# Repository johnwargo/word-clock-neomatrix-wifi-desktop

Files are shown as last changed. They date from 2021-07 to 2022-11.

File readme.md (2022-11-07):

# Word Clock NeoMatrix Wi-Fi Desktop

This repository contains a forked version of the [WORD CLOCK - NeoMatrix 8x8 Desktop Edition](https://github.com/andydoro/WordClock-NeoMatrix8x8) project by [Andy Doro](https://andydoro.com/) & [Dano Wall](https://github.com/danowall).  

I forked the project because my personal implementation of the clock got way behind time-wise, so I decided to rebuild the code for a Wi-Fi enabled device (Adafruit Feather) so it can periodically update the real-time clock (RTC) using an [Internet Time Server](https://tf.nist.gov/tf-cgi/servers.cgi) and [Network Time Protocol](https://en.wikipedia.org/wiki/Network_Time_Protocol) (NTP). 

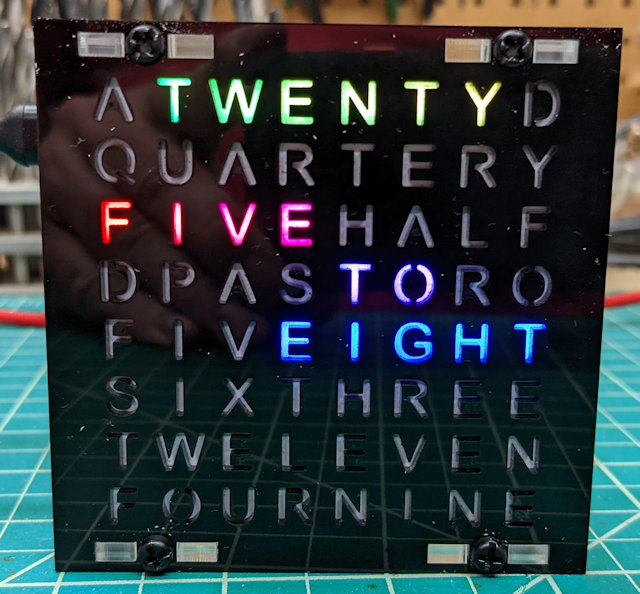
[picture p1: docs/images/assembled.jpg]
Finished Project


Here's some details for the original project:

## Original Project

* [Andy Doro Word Clock Desktop](https://andydoro.com/wordclockdesktop/)
* [Adafruit Learn Guide](https://learn.adafruit.com/neomatrix-8x8-word-clock/)
* [GitHub Repository](https://github.com/andydoro/WordClock-NeoMatrix8x8)

### Clock Grid Pattern

``` text
A T W E N T Y D
Q U A R T E R Y
F I V E H A L F
D P A S T O R O
F I V E I G H T
S I X T H R E E
T W E L E V E N
F O U R N I N E
```

Acknowledgements:

  - Thanks [Dano](https://github.com/danowall) for faceplate / 3D models & project inspiration! 

## Hardware Components

This updated version of the project uses the following hardware components:

* [Adafruit HUZZAH32 – ESP32 Feather Board](https://learn.adafruit.com/adafruit-huzzah32-esp32-feather). Make sure you order the device with 'Loose headers', you'll need those headers for the DS3231 Precision RTC FeatherWing.
* [DS3231 Precision RTC FeatherWing - RTC Add-on For Feather Boards](https://www.adafruit.com/product/3028).
* [CR1220 12mm Diameter - 3V Lithium Coin Cell Battery](https://www.adafruit.com/product/380).
* [NeoPixel NeoMatrix 8x8](https://www.adafruit.com/products/1487).
* (Optional) [Short Feather Male Headers - 12-pin and 16-pin Male Header Set](https://www.adafruit.com/product/3002); these should already come with the Feather Huzzah32.
* [Header Kit for Feather - 12-pin and 16-pin Female Header Set](https://www.adafruit.com/product/2886).
* LASER cut faceplate & enclosure (I'm using all capital letters for LASER because it is, after all, an acronym).
* Enclosure Assembly Parts:
  * 10 @ M3x12mm machine screws (bolts); enclosure assembly.
  * 4 @ M3x8mm machine screws (bolts); mounting the LED Matrix to the enclosure.
  * 14 @ M3 nuts; enclosure assembly.
  * 4 @ M2.5x12mm machine screws (bolts); mounting the Feather device to the enclosure.
  * 4 @ M2.5 nuts; mounting the Feather device to the enclosure.

## Instructions

To keep this readme as simple as possible, I moved the assembly and software configuration instructions into separate files:

1. [Electronics Assembly](docs/electronics-assembly.md)
2. [Electronics Testing](docs/electronics-testing.md)
3. [Enclosure Assembly](docs/enclosure-assembly.md)
4. [Software Configuration](docs/software.md)

## Project Updates

I've tried to maintain as much of the original code as possible; so far, I made the following changes:

* Move the sketch's configuration settings to an external file I could exclude from the repo. By doing this, and by including a separate file users must rename before compiling the project, users can refresh their local code base from the public repository without wiping out their configuration settings. 
* Removed the `DateTime theTime` global variable and declared it locally and passed it around as needed (global variables are bad).
* Added more comments explaining the code in more detail (for users who want to better understand what's happening within the sketch).
* Renamed the project files using dashes instead of camelCase; this names them consistently and, when you're working on systems where file name case matters, you won't have to deal with anything in upper case.
* Added an test sketch to quickly validate the electronics assembly before configuring and deploying the main clock sketch.
* Updated the enclosure files to accommodate the Adafruit Feather board and added the files to a separate folder in the repo
* Added LASER cutter files for a 12-inch clock face for a wall mounted unit.

For this version of the project, I selected the [Feather Huzzah 32](https://www.adafruit.com/product/3405); I became a big fan of the board's ESP32 chipset last year, so I knew the selected board had enough horsepower and memory for anything I needed.  For the Real-time Clock (RTC) board, I selected the [DS3231 Precision RTC FeatherWing - RTC Add-on For Feather Boards](https://www.adafruit.com/product/3028); its a high precision board that maintains time accuracy in different temperature conditions. 

Another reason I like this board over the Trinket used in the original project is that the Feather boards come wired with the hardware you need to easily program the board via a USB cable. The Trinket doesn't include that hardware, so you have to push a button on the device to put it in programming mode - which is really hard to do when the device is inside the enclosure.

## Clock Changes

In the original project, the code set the real-time clock using the build date/time for the Arduino Sketch running on the board. The sketch did this the first time it ran, but there was no easy way to update it later. As I mentioned in the introduction, I ran into some time leakage problems (after about a year running, the time wasn't anywhere near the actual time) so I wrote a simple modification to the code that let you reset it manually (read more in [Word Clock Time Issues](https://johnwargo.com/internet-of-things-iot/word-clock-time-issues.html)).

This version still has the original code that sets the RTC date/time using the build date/time, but since the sketch runs on an Arduino-compatible device with Wi-Fi, I can use Network Time Protocol to periodically update the RTC from the network as well. 

So, here's the order of RTC-related things in the sketch:

1. On startup, if the sketch detects that the RTC lost power (or was reset), set the RTC date/time to the sketch's build date/time.
2. On startup, if the device has a network connection (access to the Internet via Wi-Fi), use NTP to update the RTC date/time.
3. At midnight every day, if the device has a Wi-Fi connection, use NTP to update the RTC date/time to the current date/time. If the device doesn't have a network connection, the clock uses the date/time value currently in the RTC.

Some notes about the software/hardware:

* With the sketch setting the date/time at startup based on the build date/time, if the device never connects to the Internet (to use NTP) then the clock will be as accurate as it can be with the stand-alone RTC. This means that time may slip a little over time, and you may periodically have to force a reset using the article mentioned above.
* With a network connection, the device will update the RTC date/time every day which should improve overall accuracy.
* If the device loses its network connection, it will try periodically (every 5 minutes) to reconnect.

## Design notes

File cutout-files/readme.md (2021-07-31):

# World Clock NeoMatrix Wi-Fi Desktop Cutout files

This folder contains the LASER cutout files for different versions of the project:

* Desktop Enclosure Feather - this folder contains the original enclosure cutout files modified to use the Adafruit Feather board instead of the original project's Adafruit Trinket microcontroller.
* Desktop Enclosure Trinket - this folder contains the original enclosure cutout files for the original project's Adafruit Trinket microcontroller.

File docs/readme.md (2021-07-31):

# World Clock NeoMatrix Wi-Fi Desktop Documentation

To keep this readme as simple as possible, I moved the assembly and software configuration instructions into separate files:

1. [Electronics Assembly](electronics-assembly.md)
2. [Electronics Testing](electronics-testing.md)
3. [Enclosure Assembly](enclosure-assembly.md)
4. [Software Configuration](software.md)

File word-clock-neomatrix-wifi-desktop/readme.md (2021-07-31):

# World Clock NeoMatrix - Arduino Code

This folder contains the Arduino source code for the project.

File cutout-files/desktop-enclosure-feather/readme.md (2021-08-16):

# Desktop Enclosure (Feather)

This folder contains the LASER cut-out files for the word clock desktop enclosure; these files are modified from the original files provided with Andy Doro's Word Clock project for the Adafruit Feather microcontroller board.

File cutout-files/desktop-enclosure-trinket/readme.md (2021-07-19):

# Desktop Enclosure (Trinket)

This folder contains the LASER cut-out files for the word clock desktop enclosure; these are the original files provided with Andy Doro's Word Clock project for the Trinket microcontroller board.

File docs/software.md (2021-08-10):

# Word Clock (Feather) Software Configuration

This document contains information about the software configuration and installation for the Word Clock. 

## Required Software

Depending on your hardware setup and personal preferences, you'll need to make some changes to the Word Clock sketch and deploy it to the clock. You can use any text editor you want to edit the sketch's configuration settings, but you'll need one of the following Arduino development tools to compile and deploy the sketch to the clock

* [Arduino IDE](https://www.arduino.cc/en/software)
* [Arduino Web IDE](https://create.arduino.cc/editor)
* [Visual Studio Code](https://code.visualstudio.com/) with the [Arduino](https://marketplace.visualstudio.com/items?itemName=vsciot-vscode.vscode-arduino) extension.

Follow Adafruit's online instructions for configuring the developer tools for the Feather board you selected for this project.

## Required Libraries

This project uses the following Arduino libraries:

- [RTClib](https://github.com/adafruit/RTClib)
- [DST_RTC](https://github.com/andydoro/DST_RTC)
- [Adafruit_GFX](https://github.com/adafruit/Adafruit-GFX-Library)
- [Adafruit_NeoPixel](https://github.com/adafruit/Adafruit_NeoPixel)
- [Adafruit_NeoMatrix](https://github.com/adafruit/Adafruit_NeoMatrix)

To Install the libraries:

- [ ] Open the Arduino IDE, then open the Library Manager. To do this, open the **Tools** menu, then select **Manage Libraries** as shown in the following figure.

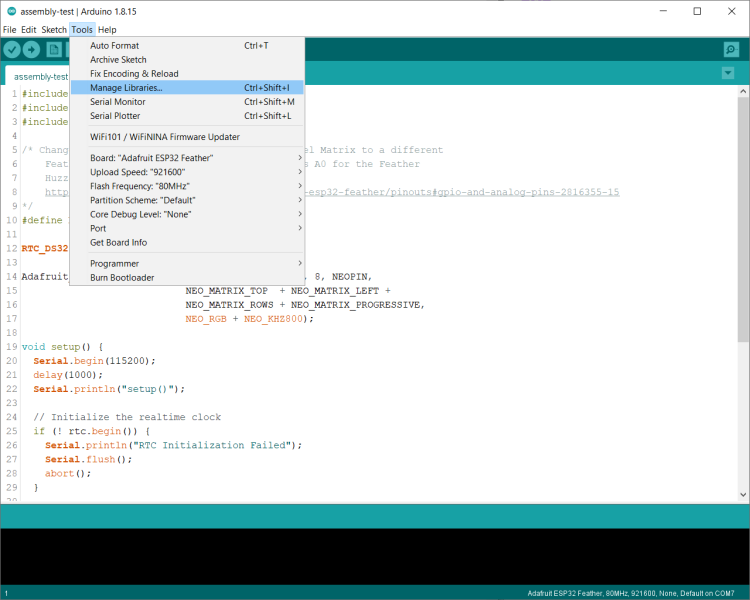
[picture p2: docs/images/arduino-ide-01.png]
Arduino IDE Tools Menu


- [ ] Locate each required library individually (its easiest to use Search) then install it into the IDE. 

**Note:** There are multiple RTC libraries, so make sure you select (and install) the right one.

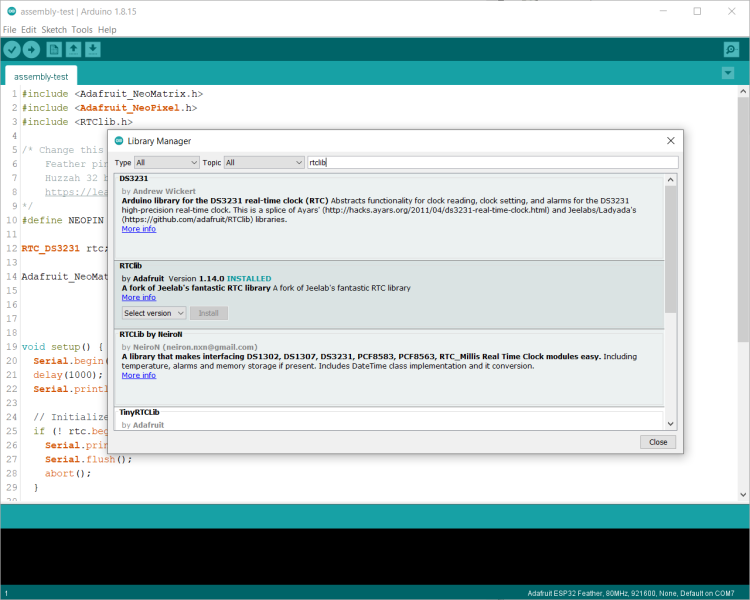
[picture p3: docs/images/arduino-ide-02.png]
Arduino IDE Library Manager


## Sketch Configuration

When I forked the original project, I pulled all of the configuration settings into a separate file, then hid that file from the repository. I then made a copy of the configuration file under a different name and included that file in the repository. I did this because if I kept the 'real' configuration file in the repo, after you make changes in the file to support your needs, any subsequent update from the repository would overwrite your changes. 

Before you try to compile and deploy the project's code, you must first copy the `config.copyme` file to `config.h`. When you're done, you'll have both files in the folder. The `config.copyme` is part of the source code repository, so any time you pull updates or changes down from GitHub, it may overwrite that file. You can make whatever changes you want to the `config.h` file, and they won't be overwritten when you update the source code from the Internet.

To do this on Microsoft Windows, you can open Windows Explorer (the file system browser app) and copy it there.  If you're comfortable with the command line, you can open a Command Prompt, navigate to the project folder, and execute the following command:

```shell
copy config.copyme config.h
```

On Linux and macOS, open a terminal window, navigate to the project folder, and execute the following command:

```shell
cp config.copyme config.h
```

If you skip this step, compilation of the sketch will generate a whole bunch of errors starting with:

```text
world-clock-neomatrix-wifi-desktop:110:54: error: 'NEOPIN' was not declared in this scope

 Adafruit_NeoMatrix matrix = Adafruit_NeoMatrix(8, 8, NEOPIN,

                                                      ^

world-clock-neomatrix-wifi-desktop:114:29: error: 'LED_CONFIG' was not declared in this scope

                             LED_CONFIG);

                             ^
```

**Note:** If you ever refresh your local files from the repository, you may want to check the project's `changelog.md` file for any new configuration settings you'll need to copy over to your project's `config.h` file.

## Configuration Settings

The following sections describe the different configuration options for the project. I tried to break them up into groups to make it easier to find the settings you're looking for. 

**Note:** Many of the settings are defined as C language `#define` components. According to the [Arduino Documentation](https://www.arduino.cc/reference/en/language/structure/further-syntax/define/):

> `#define` is a useful C++ component that allows the programmer to give a name to a constant value before the program is compiled. Defined constants in arduino don’t take up any program memory space on the chip. The compiler will replace references to these constants with the defined value at compile time.

As you modify these settings, pay special attention to the format of the constant. For example, they're not code, so there's no need to end the line with a semi-colon (;). Strings, however, must be in double quotes.

### Host

The Arduino WiFi library allows a sketch to set the device name before initializing the Wi-Fi connection. With this value set, the device identifies itself on the network with this name. [Arduino Documentation](https://www.arduino.cc/en/Reference/WiFiNINAsetHostname).

```c
#define HOST_NAME "Word Clock (ESP32)"
```

### LED Settings

The project allows you to set LED brightness for day and night through these two constants:

```c
#define DAYBRIGHTNESS 40
#define NIGHTBRIGHTNESS 20
```

You can also control the cutoff time (in hours) for day and night through these two constants:

```c
#define MORNINGCUTOFF 7  // when does daybrightness begin?   7am
#define NIGHTCUTOFF   22 // when does nightbrightness begin? 10pm
```

When the sketch starts, you can have it flash each word on the display for the number of milliseconds defined in this constant.

```c
#define FLASHDELAY 250  // delay for startup "flashWords" sequence
``` 

While the sketch displays time, the colors behind the words shift over time; this constant defines how many milliseconds pass between each color shift.

```c
#define SHIFTDELAY 100   // controls color shifting speed
```

### NeoPixel Settings

The `NEOPIN` constant defines the Feather GPIO pin connected to the `DIN` connector on the NeoMatrix. If you assembled the electronics components as instructed in the assembly documentation, you don't need to make any changes here. If you connected the NeoMatrix to a different output pin on the Feather, you must change the value here accordingly. 

The Pinout labeling on the Feather is a little weird - the instructions I provided tell you to connect the NeoMatrix `DIN` to `A0` on the Feather, but that actually corresponds to GPIO 26 which is what you see in this constant.

```c
#define NEOPIN 26  
```

If you're using the NeoMatrix board listed in the [Hardware Components](https://github.com/johnwargo/world-clock-neomatrix-8x8-wifi#hardware-components) section of the repository's `readme.md` file, then you don't need to make any changes here. If you're using different hardware, you must adjust the code to accommodate your hardware configuration using the instructions provided in [Arduino Library Use](https://learn.adafruit.com/adafruit-neopixel-uberguide/arduino-library-use).

For example, if you're using three-color (RGB) LEDs in your NeoMatrix, use the following:

```c
#define LED_CONFIG NEO_RGB + NEO_KHZ800
```

If using four-color (RGBW) LEDs in your NeoMatrix, use the following:

```c
#define LED_CONFIG NEO_GRBW + NEO_KHZ800
```

### Network Settings

The whole point of this forked project is to enable a network connection in the clock so it can automatically update its real-time clock (RTC) over the network. The constants below define the SSID and password for the Wi-Fi network. Enter the appropriate values for your local between the quote marks.

```c
#define WIFI_SSID ""
#define WIFI_PSWD ""
```

For example:

```c
#define WIFI_SSID "MyHomeNetwork"
#define WIFI_PSWD "What are you looking at?"
```

The constant below defines how many seconds the device will attempt to connect to the Wi-Fi network before it aborts the connection.

```c
#define WIFI_TIMEOUT 10 //seconds
```

### Time Settings

The settings in this section specify how the sketch deals with locale, time zone, and Daylight Savings Time.

If you live in a country or territory that observes [Daylight Saving Time](https://en.wikipedia.org/wiki/Daylight_saving_time_by_country), adjust the following constant appropriately. Use 1 if you observe DST, 0 if you don't. 

**Note:** From the original repo's notes: This is programmed for DST in the US / Canada. If your territory's DST operates differently,
you'll need to modify the code in the calcTheTime() function to make this work properly.

```c
#define OBSERVE_DST 1
```

NTP returns the current time as Greenwich Mean Time (GMT), so to display the current time for your time zone, you must provide an offset value that's automatically added to the time returned from NTP. Enter a value below calculated based on your current time zone difference from GMT as follows:

> GMT_OFFSET * 3600

For example, I live in GMT-5, so I'd calculate mine as:

> -5 * 3600 = -18000

Examples:

* GMT-5 = -18000
* GMT-4 = -14400
* GMT-3 = -10800
* GMT-2 = -7200
* GMT-1 = -3600
* GMT = 0
* GMT+1 = 3600
* GMT+2 = 7200
* GMT+3 = 10800
* GMT+4 = 14400
* GMT+5 = 18000

So, if your clock operates at GMT, or you want the clock to show GMT, use the following:

```c
#define GMT_OFFSET 0  
```

For a clock running in Charlotte, North Carolina (US), use:

```c
#define GMT_OFFSET -18000
```

Every minute, the clock prints the current date/time value to the Serial Monitor. To display the date/time in US format (Month/Day/Year Hour:Minute), use:

```c
#define USE_US_DATE_TIME_FORMAT
```

To print the date/time value to the Serial Monitor in European format (Year-Month-Day 24Hour:Minute), comment out the constant like this: 

```c
// #define USE_US_DATE_TIME_FORMAT
```

The original project's author published a library that automatically deals with Daylight Savings Time issues in the sketch. You can control which rules the library uses for the clock. 

To use the US rules, comment out the EU string as shown in the following example:

```c
const char rulesDST[] = "US"; // US DST rules
// const char rulesDST[] = "EU";   // EU DST rules
```

To use the European rules, comment out the US string as shown in the following example:

```c
// const char rulesDST[] = "US"; // US DST rules
const char rulesDST[] = "EU";   // EU DST rules
```

## Deploying the Software

Once you've made all of the required changes to the configuration file, compile and deploy the sketch to your Word Clock and enjoy!

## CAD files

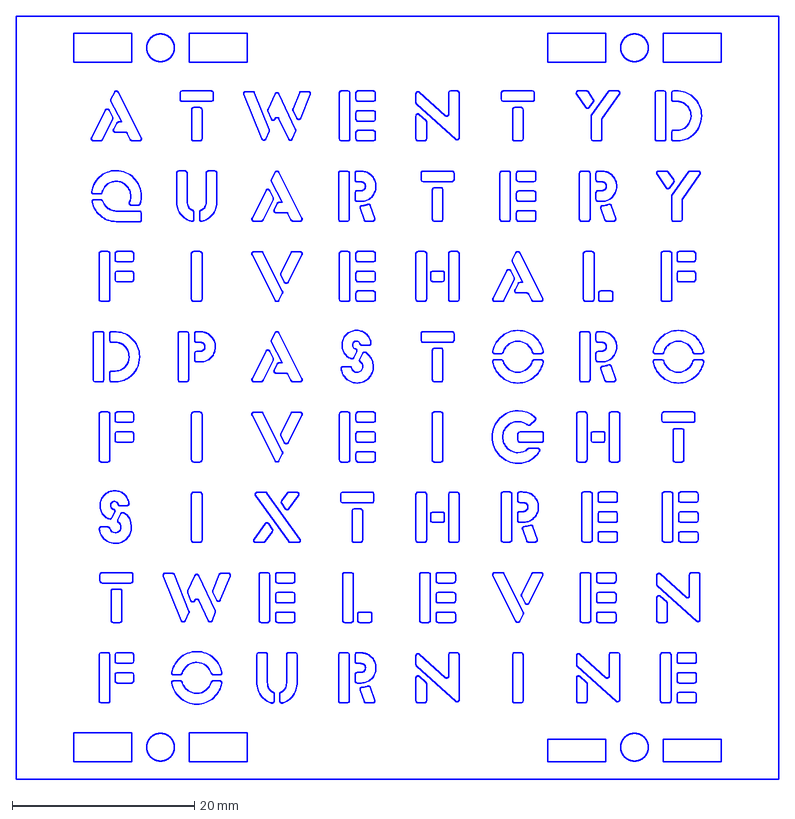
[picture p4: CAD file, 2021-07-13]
cutout-files/desktop-enclosure-trinket/wordclock_faceplate_ponoko.dxf
83.8 x 83.8 mm

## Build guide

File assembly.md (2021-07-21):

# Word Clock Assembly

## Hardware Components

* [Adafruit HUZZAH32 – ESP32 Feather Board](https://learn.adafruit.com/adafruit-huzzah32-esp32-feather)
* [DS3231 Precision RTC FeatherWing - RTC Add-on For Feather Boards](https://www.adafruit.com/product/3028)
* [NeoPixel NeoMatrix 8x8](https://www.adafruit.com/products/1487)
* LASER cut faceplate & enclosure
* Enclosure bolts
* Enclosure Nuts
* Feather mounting bolts
* Feather mounting nuts
* 

buy the hardware

Solder the components together

Assemble the case

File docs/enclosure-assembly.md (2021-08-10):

# World Clock NeoMatrix Wi-Fi Desktop Enclosure Assembly

This documnet contains the complete instructions for assembling the Word Clock enclosure (assuming you use the enclosure plans included with this project).

**Note:** I asked [Muzammil Patel](https://www.fiverr.com/muzammil_patel) on Fiverr to adjust the original project's enclosure to accommodate the Feather line of Microcontrollers. He added additional bolt holes and moved the USB Connector opening. Unfortunately, even though the folks at Adafruit published a specification for the [Feather](https://learn.adafruit.com/adafruit-feather/feather-specification) series of microcontroller boards, they've not done a very good job sticking with that specification. For the Feather Huzzah boards (both the ESP8266 and ESP32), they adjusted the size and position of the two bolt holes on the opposite side of the board from the USB connector. I hope to have an updated version of the design that accommodates different size feathers, but if I don't you may have to tweak the enclosure holes to fit the Feather board you selected for this project.

I used [Ponoko](https://www.ponoko.com/) to LASER cut the enclosure for me, I love those guys and they usually do a great job for me. When you look at the enclosure pieces, they'll start looking something like this:

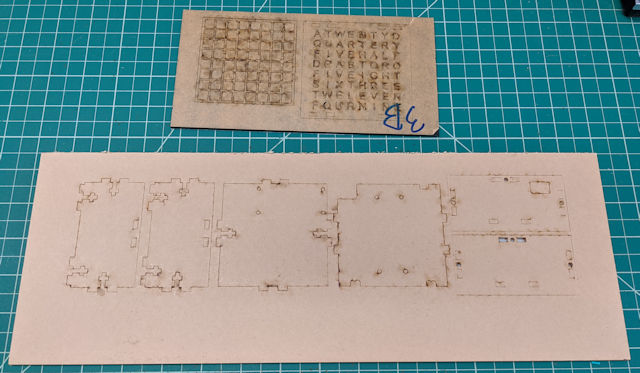
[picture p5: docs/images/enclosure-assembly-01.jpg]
Enclosure Image #1


- [ ] Ponoko uses a big piece of masking tape to hold the pieces together. Remove that tape and all of the parts fall out. The faceplate and the grid protector drop a lot of little parts, so make sure you do this over a table or desktop so you can collect the extra bits and throw them away (or keep them for some other project).

- [ ] The enclosure pieces have even more tape on both sides of each piece, so you must peel those off of both sides of the pieces before continuing. You can see the tape in the following image.

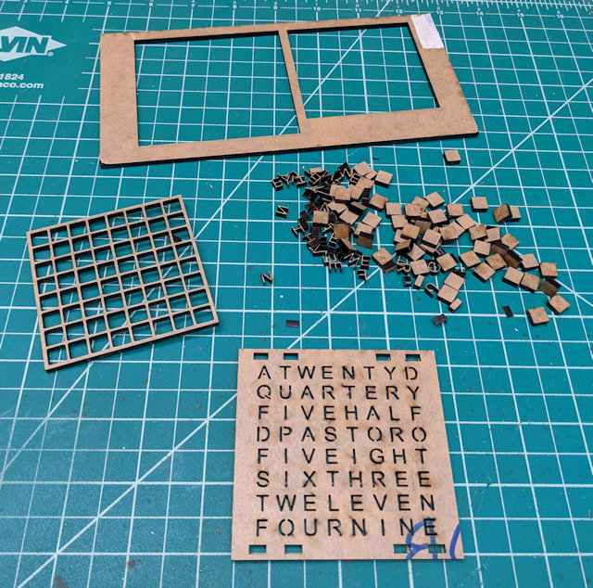
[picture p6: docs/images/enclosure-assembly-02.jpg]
Enclosure Image #2


- [ ] Mount the NeoMatrix to to the enclosure's top panel using 4 M3x8mm machine screws/bolts as shown in the following figure. I pushed the bolts through the top of the NeoMatrix so they'd sit flush with the top of the board, if you did it the other way, the nuts would cover part of the NeoMatrix's NeoPixels. 

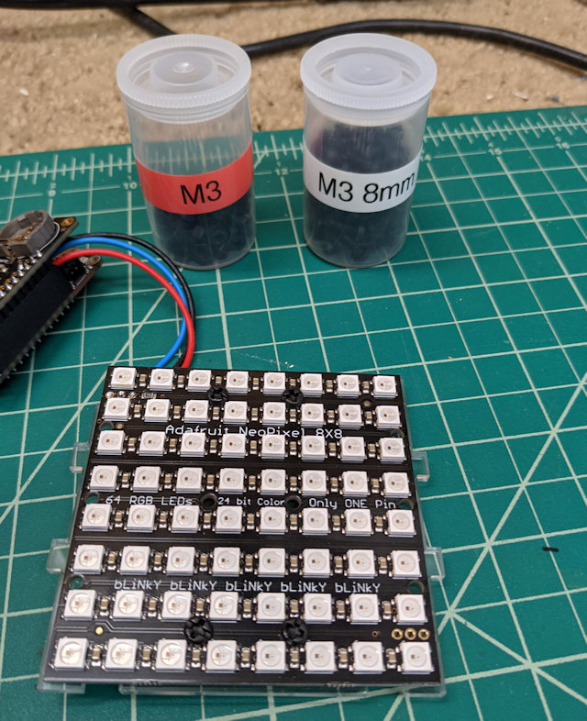
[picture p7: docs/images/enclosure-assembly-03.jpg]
Enclosure Image #3


The three wires connecting the Feather assembly to the NeoMatrix fit through a special notch in the enclosure; the wires should not be pressed up against the enclosure anywhere, they should have an unencumbered position off the back of the NeoMatrix as shown in the following image:

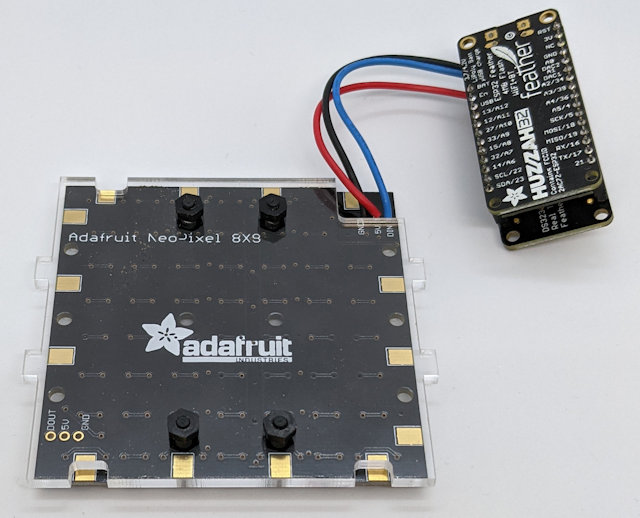
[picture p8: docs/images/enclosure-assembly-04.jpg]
Enclosure Image #4


- [ ] Next, mount the Feather Assembly on the enclosure bottom as shown in the following image. You can use 2 M2.5x10mm or M2.5x12mm bolts for the holes near the USB connector. Depending on the Feather board you select, you may be able to use the same size bolts for the other holes, but for the Feather Huzzah boards you will need M2x10 or M2x12mm bolts.

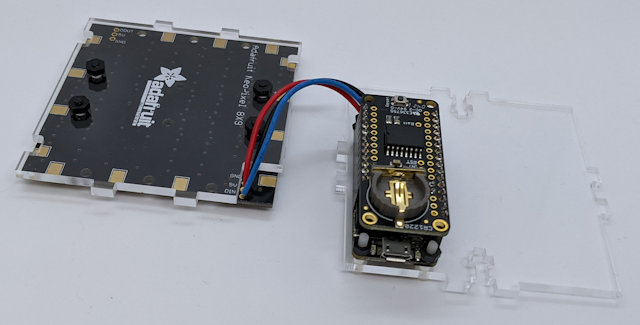
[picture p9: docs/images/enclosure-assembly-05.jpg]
Enclosure Image #5


**Note:** I found that I had to tweak the Huzzah board to fit the bolts through the holes. The Huzzah boards have a Wi-Fi antenna covering part of the mounting holes, so I had to use a drill to drill through the holes and antenna to allow clear passage. Be careful doing this; you must make sure you don't cut the antenna traces when you do this - only drill through the edge of the antenna panel to open a space for the bolts.

- [ ] Mount the enclosure's end panel over the end of the board with the USB connector as shown in the following image. Use an M3x12mm bolt and nut to complete the installation as shown in the figure.

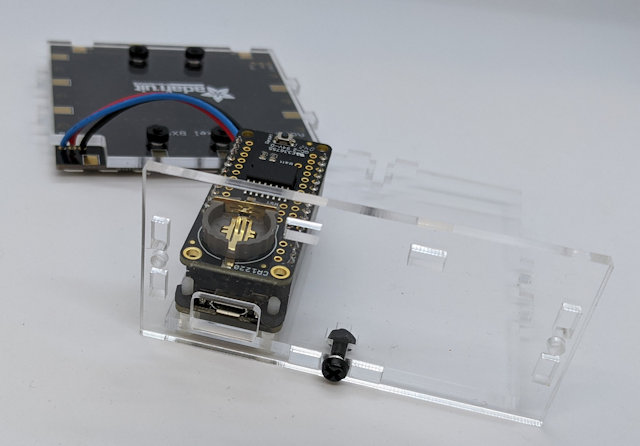
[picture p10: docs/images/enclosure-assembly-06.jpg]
Enclosure Image #6


- [ ] Mount one of the side panels to the assembly as shown in the following figure. Use an M3x12mm bolt and nut to complete the installation as shown in the figure.

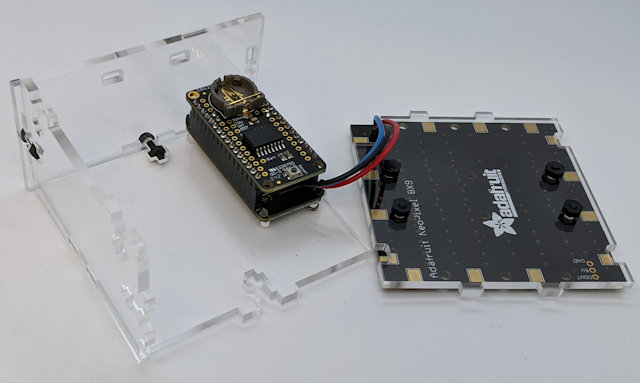
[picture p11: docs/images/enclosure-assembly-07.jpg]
Enclosure Image #7


- [ ] Repeat the same process for the other side panel as shown in the following figure. 

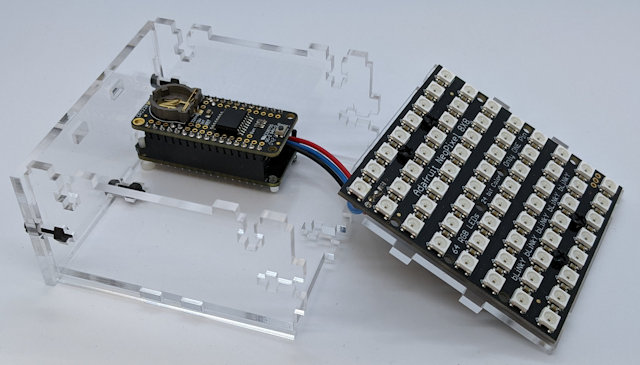
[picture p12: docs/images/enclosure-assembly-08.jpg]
Enclosure Image #8


At this point, only three sides of the enclosure are assembled; you need that remaining end open as you fit in the NeoMatrix panel into the enclosure.

- [ ] Slide the assembled NeoMatrix panel into the assembled enclosure with the upper-left corner of the NeoMatrix on the same side as the Feather assembly as shown in the following image. Next, insert the remaining side panel and use three M3x12mm bolts and nuts to hold the panels together. 

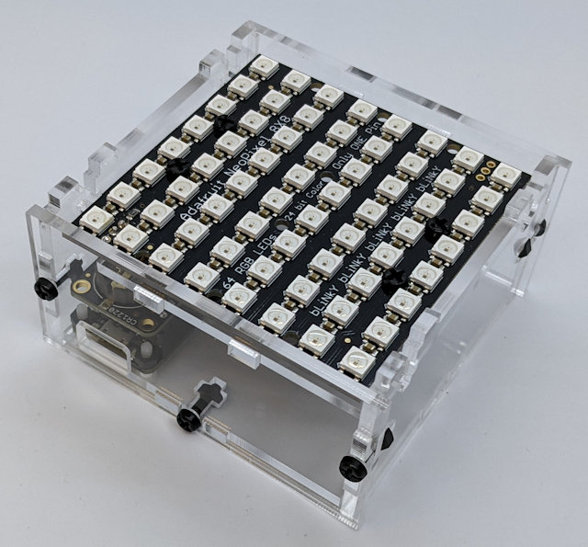
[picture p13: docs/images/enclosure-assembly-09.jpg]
Enclosure Image #9


This is where some of this gets tricky because you'll probably start dropping nuts into the enclosure as you try to fit it all together. What did when assembling this was to hold the assumbly upside down (with the nut opening pointing down), with the assembly in this position, I could push the nut into the slot and hold it in place via gravity as I inserted the bolt and twisted it in place. 

- [ ] If you 3D printed the pixel guard  (shown in the following figure) then skip this step. If you LASER cut the piece you have some extra work to do before you can complete assembly. When you place the grid over the NeoMatrix, you should notice that the bolt heads mounting the NeoMatrix to the enclosure keep the pixel guard from resting evenly against the NeoMatrix. You must cut or grind the underside of the pixel guard to make room for the bolts. If you look closely at the picture, you can see the indentations I cut into the pixel guard using a Dremel. 

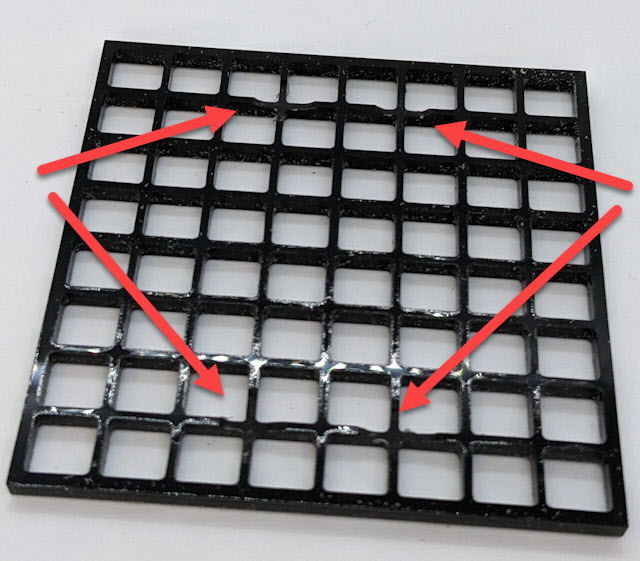
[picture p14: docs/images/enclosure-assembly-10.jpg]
Enclosure Image #10


- [ ] Using the pixel guard as a template, cut a piece of white paper to the dimensions of the pixel guard. Place the pixel guard on top of the NeoMatrix, then place the piece of paper on top of the pixel guard as shown in the following image.

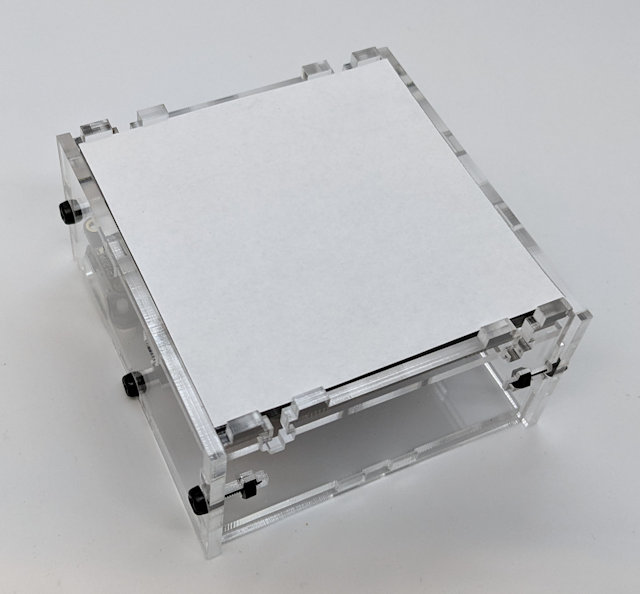
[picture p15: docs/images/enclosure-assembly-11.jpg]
Enclosure Image #11


- [ ] Finally, mount the Word Clock face on top of the enclosure using 4 M3x12mm bolts and nuts to complete the installation as shown in the figure.

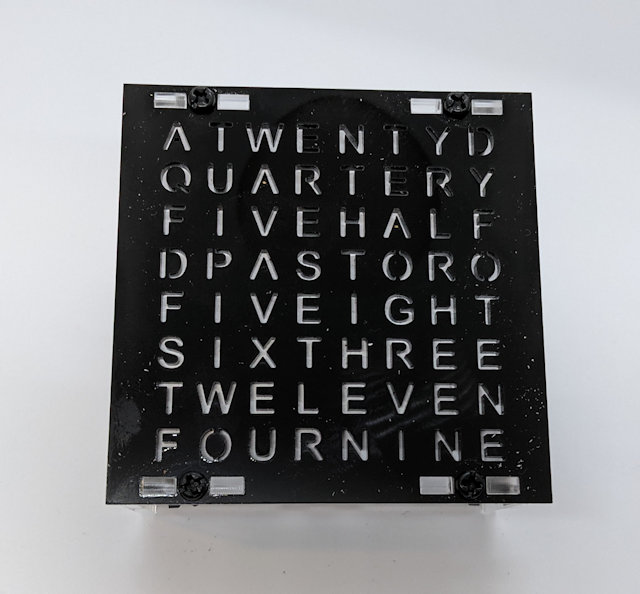
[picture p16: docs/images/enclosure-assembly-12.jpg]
Enclosure Image #12


Here's a picture of the completely assembled and operational word clock.

Enclosure Image #13

---

The next step is to install the Word Clock sketch to the device; for complete instructions, refer to [Software](software.md).

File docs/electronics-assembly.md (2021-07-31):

# World Clock NeoMatrix Wi-Fi Desktop Electronics Assembly

This document contains the complete instructions for assemblying the electronics components for the project. 

- [ ] Cut three lengths of stranded wire (22ga or so) to a length of 4 inches. You can use the same color for all, but I wouldn't (because this will just get confusing later on if you do). Instead, use three separate colors: red and black (for my 5V connection [red] and ground [black] wire) plus one other color.

- [ ] Look at the back of the NeoPixel Matrix board and locate the three connectors (highlighted in orange) to the right of the board name in the following figure. In the following three steps, you must use the highlighted connectors (the board has two sets of connectors, and if you use the wrong ones things just won't work correctly). 

The enclosure has an opening to accommodate wires connected to the highlighted connectors. If you use the wrong ones, the matrix will be unside-down in the enclosure, and the clock will never display the correct time. Get it right the first time, please.

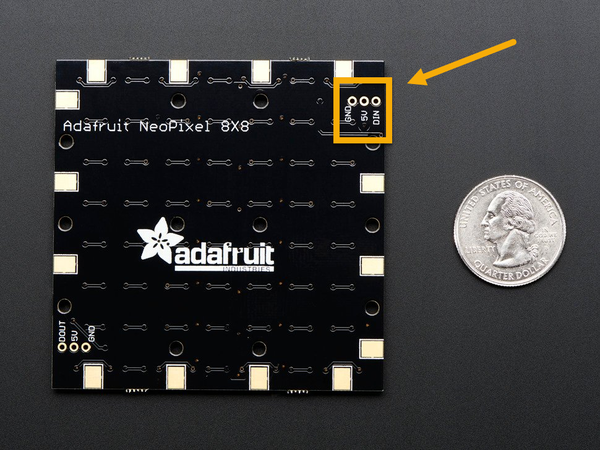
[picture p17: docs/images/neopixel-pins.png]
Adafruit NeoPixel NeoMatrix 8x8 Connections


- [ ] (Assuming you have red, black, and some other color wire) Strip 1/4 inch of insulation from both ends of the Black wire, then solder one end of the wire to the `GND` connector highlighted in the previous figure. 

- [ ] Strip 1/4 inch of insulation from both ends of the Red wire, then solder one end of the wire to the 5V connector highlighted in the previous figure.

- [ ] Strip 1/4 inch of insulation from both ends of the remaining wire, then solder one end of the wire to the DIN connector highlighted in the previous figure.

- [ ] Grab the DS3231 Precision RTC FeatherWing board and solder the male headers to the board. The easiest way to do this is to insert the bottom posts of the header (the longer pins) into a breadboard, then set the board on top of the exposed header pins (as shown in the following figure). Make sure you use the outside (closest to the edge of the board) holes for the headers as shown in the figure, then solder each of the pins to the board.

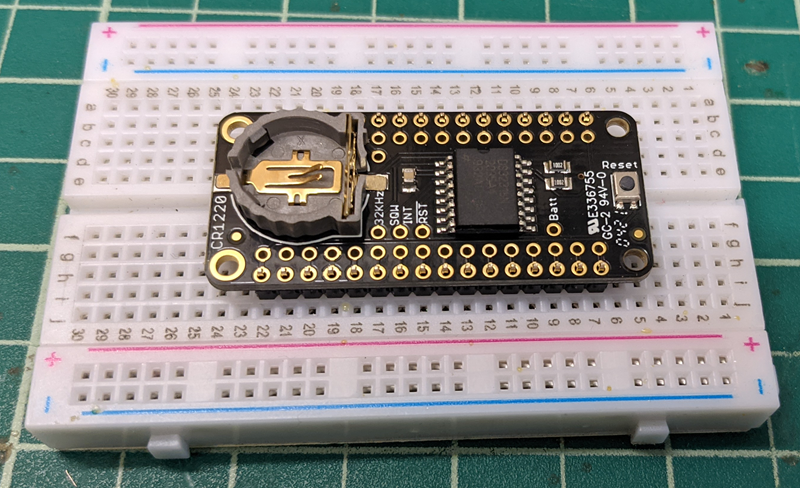
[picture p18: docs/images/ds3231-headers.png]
DS3231 Precision RTC FeatherWing Headers


- [ ] On the DS3231 Precision RTC FeatherWing board, look for the connections highlighted in the following figure. 

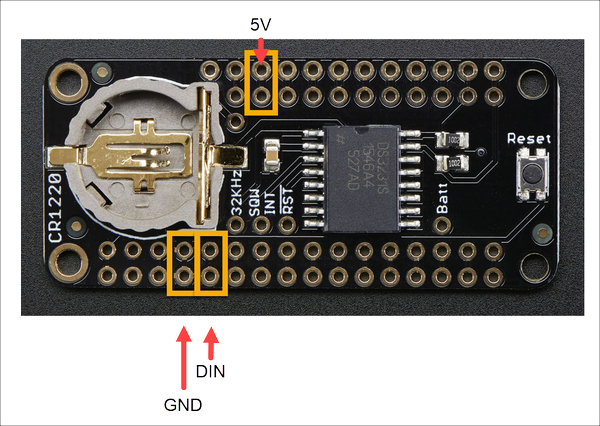
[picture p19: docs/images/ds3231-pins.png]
DS3231 Precision RTC FeatherWing Connections


**Note:** When I connected the wires to the board (described in the next three steps) I ran the wires up from the underside of the board and soldered them on the top

- [ ] Connect the exposed end of the Black wire to the GND Connection highlighted in the figure and solder it in place.

- [ ] Connect the exposed end of the Red wire to the 5V Connection highlighted in the figure and solder it in place.

- [ ] Connect the exposed end of the other color (mine is blue) wire to the DIN Connection highlighted in the figure and solder it in place. This is the A0 pin on the Feather.

When you're all done, the assembly should look similar to the following:

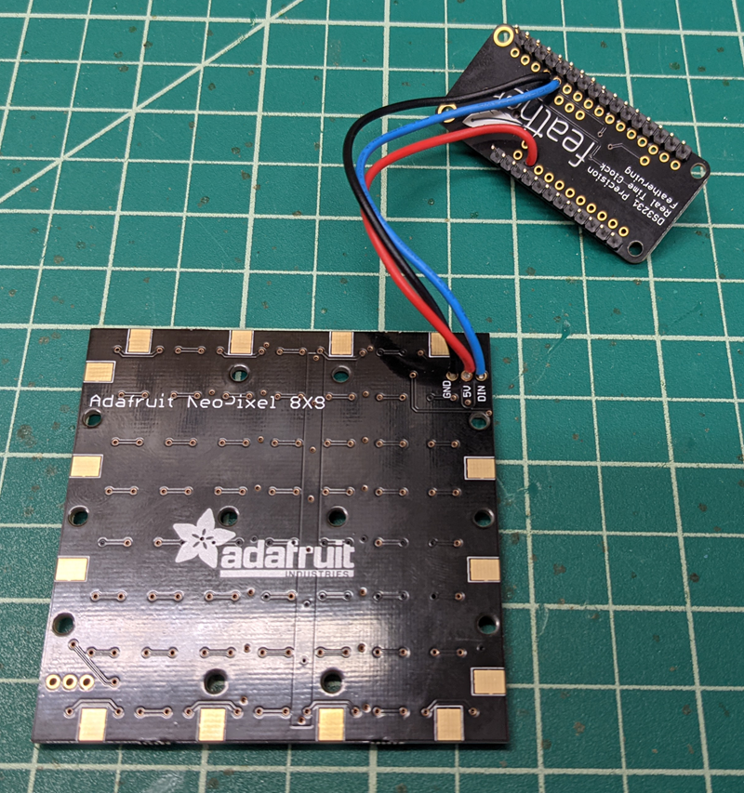
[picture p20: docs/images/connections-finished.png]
Completed soldered connections


- [ ] Grab the Feather Huzzah32 board and insert the female headers through the pins on the top of the board as shown in the following figure. Next, solder the pins on the underside of the board.

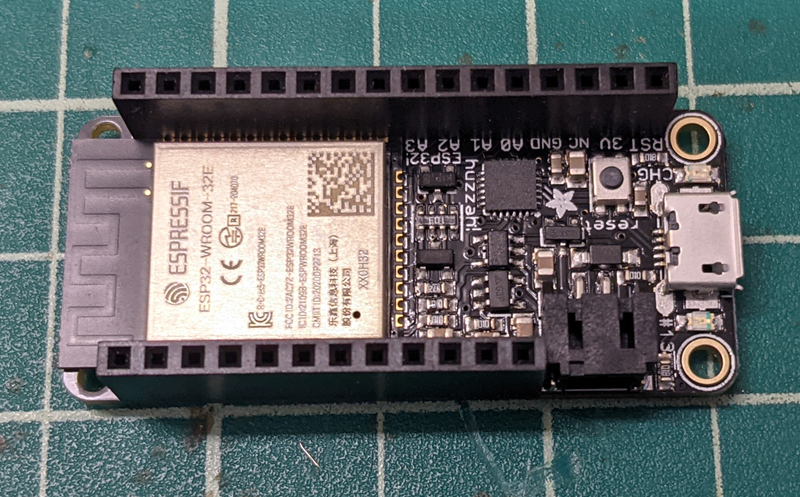
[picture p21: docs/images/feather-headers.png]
Feather With Female Headers


- [ ] Stack the DS3231 Precision RTC FeatherWing board on top of the Feather Huzzah 32 as shown in the following figure:

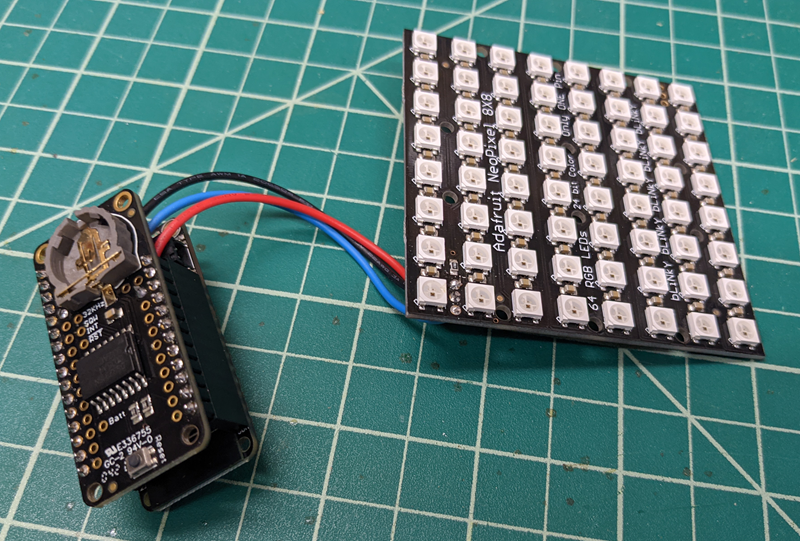
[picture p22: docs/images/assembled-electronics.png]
Fully assembled electronics


- [ ] Finally, insert the CR1220 battery into the battery holder on top of the Feather assembly

---

To help validate correct assembly, I included a simple tester application with the project. To view instructions on how to test the hardware, refer to [Electronics Testing](electronics-testing.md). To skip testing the hardware and jump ahead to assembling the enclosure refer to [Enclosure Assembly](enclosure-assembly.md).

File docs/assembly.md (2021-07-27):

# Word Clock (Feather) Assembly

Filet mignon jowl chislic pork chop capicola short loin. Corned beef biltong tri-tip, cupim prosciutto jerky pastrami rump kielbasa beef ribs tongue sausage landjaeger. Ham pork chop kevin landjaeger, fatback prosciutto turducken shoulder capicola. Swine pork belly sirloin bresaola short ribs tenderloin.

## Hardware Components

Pork loin filet mignon burgdoggen pig frankfurter jowl. Biltong jowl prosciutto, chuck alcatra hamburger pork chop sirloin pork belly. Pig flank pancetta brisket. Shank pancetta picanha, ham leberkas cupim landjaeger boudin jowl. Boudin meatloaf ham hock pork chop strip steak andouille.

* [Adafruit HUZZAH32 – ESP32 Feather Board](https://learn.adafruit.com/adafruit-huzzah32-esp32-feather)
* [DS3231 Precision RTC FeatherWing - RTC Add-on For Feather Boards](https://www.adafruit.com/product/3028)
* [CR1220 12mm Diameter - 3V Lithium Coin Cell Battery](https://www.adafruit.com/product/380)
* [NeoPixel NeoMatrix 8x8](https://www.adafruit.com/products/1487)
* [Short Feather Male Headers - 12-pin and 16-pin Male Header Set](https://www.adafruit.com/product/3002)
* [Header Kit for Feather - 12-pin and 16-pin Female Header Set](https://www.adafruit.com/product/2886)
* LASER cut faceplate & enclosure
* Enclosure Assembly Parts:
  * 12mm M3 bolts (10 each) for assembling the enclosure  
  * 8mm M3 bolts with nuts (4 each) for mounting the LED Matrix to the enclosure
  * M3 nuts (14 each) for assembling the enclosure
  * 8mm M2.5 bolts (4 each) for mounting the Feather device to the enclosure
  * M2.5 nuts (8 each) for mounting the Feather device to the enclosure

## Assembly Instructions

- [ ] Cut three lengths of stranded wire (22ga or so) to a length of 4 inches. You can use the same color for all, but I wouldn't (because this will just get confusing later on if you do). Instead, use three separate colors: red and black (for my 5V connection [red] and ground [black] wire) plus one other color.

- [ ] Look at the back of the NeoPixel Matrix board and locate the three connectors (highlighted in orange) to the right of the board name in the following figure. In the following three steps, you must use the highlighted connectors (the board has two sets of connectors, and if you use the wrong ones things just won't work correctly). 

The enclosure has an opening to accommodate wires connected to the highlighted connectors. If you use the wrong ones, the matrix will be unside-down in the enclosure, and the clock will never display the correct time. Get it right the first time, please.

Adafruit NeoPixel NeoMatrix 8x8 Connections

- [ ] (Assuming you have red, black, and some other color wire) Strip 1/4 inch of insulation from both ends of the Black wire, then solder one end of the wire to the `GND` connector highlighted in the previous figure. 

- [ ] Strip 1/4 inch of insulation from both ends of the Red wire, then solder one end of the wire to the 5V connector highlighted in the previous figure.

- [ ] Strip 1/4 inch of insulation from both ends of the remaining wire, then solder one end of the wire to the DIN connector highlighted in the previous figure.

- [ ] Grab the DS3231 Precision RTC FeatherWing board and solder the male headers to the board. The easiest way to do this is to insert the bottom posts of the header (the longer pins) into a breadboard, then set the board on top of the exposed header pins (as shown in the following figure). Make sure you use the outside (closest to the edge of the board) holes for the headers as shown in the figure, then solder each of the pins to the board.

DS3231 Precision RTC FeatherWing Headers

- [ ] On the DS3231 Precision RTC FeatherWing board, look for the connections highlighted in the following figure. 

DS3231 Precision RTC FeatherWing Connections

**Note:** When I connected the wires to the board (described in the next three steps) I ran the wires up from the underside of the board and soldered them on the top

- [ ] Connect the exposed end of the Black wire to the GND Connection highlighted in the figure and solder it in place.

- [ ] Connect the exposed end of the Red wire to the 5V Connection highlighted in the figure and solder it in place.

- [ ] Connect the exposed end of the other color (mine is blue) wire to the DIN Connection highlighted in the figure and solder it in place. This is the A0 pin on the Feather.

When you're all done, the assembly should look similar to the following:

Completed soldered connections

- [ ] Grab the Feather Huzzah32 board and insert the female headers through the pins on the top of the board as shown in the following figure. Next, solder the pins on the underside of the board.

Feather With Female Headers

- [ ] Stack the DS3231 Precision RTC FeatherWing board on top of the Feather Huzzah 32 as shown in the following figure:

Fully assembled electronics

- [ ] Finally, insert the CR1220 battery into the battery holder on top of the Feather assembly

- [ ] 

- [ ] 

- [ ] 

- [ ] 

- [ ] 

- [ ] 

- [ ] 

- [ ] 

- [ ] 

- [ ] 

- [ ] 

- [ ] 

- [ ] 

- [ ] 

- [ ] 

- [ ] 

Assemble the case

- [ ] 

![]()

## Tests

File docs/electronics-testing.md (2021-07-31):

# World Clock NeoMatrix Wi-Fi Desktop Electronics Testing

This document contains the complete instructions for testing the electronics components for the project. For instructions on how to assemble the electronics, refer to [Electronics Assembly](electronics-assembly.md).

I added this document because I figured you'd want to test the hardware configuration before completing the enclosure assembly. To help you, I wrote a simple [test sketch](https://github.com/johnwargo/world-clock-neomatrix-8x8-wifi/tree/main/assembly-test) and included it with the project.

> You may have to tweak the configuration of the test sketch if you changed any of the hardware for the project or connected the NeoPixel Matrix to a different output port on the Feather device.

These instructions assume you're comfortible using the Arduino IDE (desktop or web) to compile and deploy Arduino sketches. I don't use the arduino Web IDE, so what you'll find here are instructions for the desktop IDE.

- [ ] Connect the electronics assembly to the computer system using a USB cable.

- [ ] Open the Arduino IDE, then open the test sketch located in the repositories `assembly-test` folder. The sketch is called, unsurprisingly, `assembly-test.ini`.

- [ ] In the Arduino IDE, open the Library Manager. To do this, open the **Tools** menu, then select **Manage Libraries** as shown in the following figure.

Arduino IDE Tools Menu

- [ ] Install the **Adafruit NeoMatrix** library, the **Adafruit NeoPixel** library, and the Adafruit version of the **RTC** Library (RTClib). An example of the RTC Library is shown in the following figure. There are multiple RTC libraries, so make sure you select (and install) the right one.

Arduino IDE Library Manager

- [ ] At the top of the sketch, you'll see a define called `NEOPIN`; if you assembled the electronics components as instructed in the documentation, you won't need to make any changes here. If you connected the NeoMatrix to a different output pin on the Feather, you'll need to change the value here accordingly. 

The Pinout labeling on the Feather is a little weird - the instructions I provided tell you to connect the NeoMatrix `DIN` to `A0` on the Feather, but that actually corresponds to GPIO 26 which is what you see in this define.

- [ ] Later in the sketch, you'll see the following code:

```c
Adafruit_NeoMatrix matrix = Adafruit_NeoMatrix(8, 8, NEOPIN,
                            NEO_MATRIX_TOP  + NEO_MATRIX_LEFT +
                            NEO_MATRIX_ROWS + NEO_MATRIX_PROGRESSIVE,
                            NEO_RGB + NEO_KHZ800);

```

This is the code that initializes the NeoMatrix. If you're using the NeoMatrix board listed in the [Hardware Components](https://github.com/johnwargo/world-clock-neomatrix-8x8-wifi#hardware-components) section of the repository's `readme.md` file, then you won't need to make any changes here. If you're using different hardware, you must adjust the initialization code to accommodate your hardware configuration using the instructions provided in [Arduino Library Use](https://learn.adafruit.com/adafruit-neopixel-uberguide/arduino-library-use).

- [ ] Configure the IDE for the Feather board configuration, setting the Board, Port, and Programmer as described in the [Adafruit HUZZAH32 - ESP32 Feather](https://learn.adafruit.com/adafruit-huzzah32-esp32-feather) documentation. 

- [ ] Compile and deploy the sketch to the device. When the device reboots, the NeoMatrix will simultaneously blink all of its LEDs blue (one second on, one second off) until you remove power or replace the sketch with something. If the LEDs don't blink, then you have some hardware troubleshooting to do.

- [ ] To see what's going on in the sketch, open the IDE's Serial Monitor and it will display similar information to what's shown in the following figure (I changed the output after I took the screen shot, so it will be slightly off):

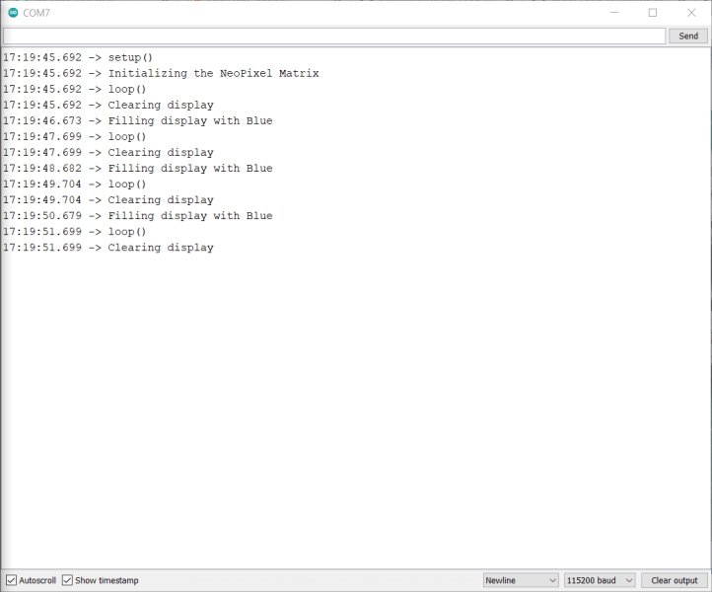
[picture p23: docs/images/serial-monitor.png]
Arduino IDE Serial Monitor


If the sketch cannot detect the RTC, it will display a message in the monitor then abort the sketch - this will be clearly reflected in the Serial Monitor's output. This too is something you'll have to troubleshoot on your own.

---

Next step is to assemble the enclosure (with the electronic components), you can find instructions in [Enclosure Assembly](enclosure-assembly.md).

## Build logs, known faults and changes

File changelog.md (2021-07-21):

# Word Clock Change Log

Nothing here yet.

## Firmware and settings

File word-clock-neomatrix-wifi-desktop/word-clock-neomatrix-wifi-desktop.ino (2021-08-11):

/*
   WORD CLOCK - 8x8 NeoPixel Desktop Edition
   by Andy Doro

   A word clock using NeoPixel RGB LEDs for a color shift effect.

   Software:

   This code requires the following libraries:

   - RTClib https://github.com/adafruit/RTClib
   - DST_RTC https://github.com/andydoro/DST_RTC
   - Adafruit_GFX https://github.com/adafruit/Adafruit-GFX-Library
   - Adafruit_NeoPixel https://github.com/adafruit/Adafruit_NeoPixel
   - Adafruit_NeoMatrix https://github.com/adafruit/Adafruit_NeoMatrix

   grid pattern

    A T W E N T Y D
    Q U A R T E R Y
    F I V E H A L F
    D P A S T O R O
    F I V E I G H T
    S I X T H R E E
    T W E L E V E N
    F O U R N I N E

    Acknowledgements:
    - Thanks Dano for faceplate / 3D models & project inspiration!
*/

// ==============================================================================
/*
    Updated by John M. Wargo, July, 2021
    Updated the code to use the Wi-Fi enabled Adafruit Feather devices
    so the code updates the date/time once a day via Network Time
    Protocol (NTP) over the Wi-Fi network.

    Also refactored the code to move configuration settings to an
    external file to make it easier to separate code and config
    (for future updates).
*/
// ==============================================================================

#include <Adafruit_GFX.h>
#include <Adafruit_NeoMatrix.h>
#include <Adafruit_NeoPixel.h>
#include <DST_RTC.h>
#include <NTPClient.h>
#include <RTClib.h>
#include <strings.h>
#include <WiFi.h>
#include <WiFiUdp.h>

// This project's libraries
#include "config.h"

char DateAndTimeString[20];

// define how to write each of the words
// 64-bit "mask" for each pixel in the matrix- is it on or off?
uint64_t mask;

// define masks for each word. we add them with "bitwise or" to generate a mask for the entire "phrase".
#define MFIVE    mask |= 0xF00000000000        // these are in hexadecimal
#define MTEN     mask |= 0x5800000000000000
#define AQUARTER mask |= 0x80FE000000000000
#define TWENTY   mask |= 0x7E00000000000000
#define HALF     mask |= 0xF0000000000
#define PAST     mask |= 0x7800000000
#define TO       mask |= 0xC00000000
#define ONE      mask |= 0x43
#define TWO      mask |= 0xC040
#define THREE    mask |= 0x1F0000
#define FOUR     mask |= 0xF0
#define FIVE     mask |= 0xF0000000
#define SIX      mask |= 0xE00000
#define SEVEN    mask |= 0x800F00
#define EIGHT    mask |= 0x1F000000
#define NINE     mask |= 0xF
#define TEN      mask |= 0x1010100
#define ELEVEN   mask |= 0x3F00
#define TWELVE   mask |= 0xF600
#define ANDYDORO mask |= 0x8901008700000000

// Used to define the LEDs to illuminate when connecting to Wi-Fi
// and the NTP server
#define LETTER_W 2
#define LETTER_T 1

char daysOfTheWeek[7][12] = {"Sunday", "Monday", "Tuesday", "Wednesday", "Thursday", "Friday", "Saturday"};

RTC_DS3231 rtc; // Establish clock object
DST_RTC dst_rtc; // DST object

int lastMinute = -1;

WiFiUDP ntpUDP;
NTPClient timeClient(ntpUDP);

// Parameter 1 = number of pixels in the strip
// Parameter 2 = Arduino pin number (most are valid)
// Parameter 3 = pixel type flags, add together as needed:
//   NEO_KHZ800  800 KHz bitstream (most NeoPixel products w/WS2812 LEDs)
//   NEO_KHZ400  400 KHz (classic 'v1' (not v2) FLORA pixels, WS2811 drivers)
//   NEO_GRB     Pixels are wired for GRB bitstream (most NeoPixel products)
//   NEO_RGB     Pixels are wired for RGB bitstream (v1 FLORA pixels, not v2)
//Adafruit_NeoPixel matrix = Adafruit_NeoPixel(64, NEOPIN, NEO_GRB + NEO_KHZ800);
// configure for 8x8 neopixel matrix
Adafruit_NeoMatrix matrix = Adafruit_NeoMatrix(8, 8, NEOPIN,
                            NEO_MATRIX_TOP  + NEO_MATRIX_LEFT +
                            NEO_MATRIX_ROWS + NEO_MATRIX_PROGRESSIVE,
                            // from the external config file (user configurable based on hardware)
                            LED_CONFIG);

void setup() {
  DateTime theTime;

  Serial.begin(115200);
  delay(2000);

  // set pinmodes
  pinMode(NEOPIN, OUTPUT);

  // Initialize the realtime clock
  if (! rtc.begin()) {
    Serial.println("\nUnable to initialize RTC");
    Serial.flush();
    abort();
  }
  // Check to see if the RTC has a time set
  // We don't really need to do this since we're going to get the time from
  // the network, but the RTC allows this thing to work even if the network
  // is down for a long period. Need to think about this.
  if ( !rtc.lostPower()) {
    // set the RTC time to the compile date/time on the sketch
    Serial.println("\nSetting RTC to sketch time");
    rtc.adjust(DateTime(__DATE__, __TIME__));
    // DST? If we're in it, let's subtract an hour from the RTC time to keep our DST calculation correct. This gives us
    // Standard Time which our DST check will add an hour back to if we're in DST.
    DateTime standardTime = rtc.now();
    if (dst_rtc.checkDST(standardTime) == true) { // check whether we're in DST right now. If we are, subtract an hour.
      standardTime = standardTime.unixtime() - 3600;
    }
    rtc.adjust(standardTime);

    // Double-check by pulling the time from the clock
    theTime = getAdjustedTime();
    // and printing it to the monitor
    printTimeValue(theTime);
  }

  matrix.begin();   // Initialize the NeoMatrix
  clearDisplay();   // empty/clear the display

  // Now, show the LED we're going to use to indicate we're connecting to Wi-Fi
  matrix.setPixelColor(LETTER_W, 0, 0, 255);  // Turn on the 'W' (Wi-Fi) LED
  matrix.show();

  int loopCounter = 0;  // number of times we looped through the connecting loop
  // Connect to the Wi-Fi network
  WiFi.setHostname(HOST_NAME);
  Serial.print("Connecting to the '");
  Serial.print(WIFI_SSID);
  Serial.print("' network");
  WiFi.begin(WIFI_SSID, WIFI_PSWD);
  while (WiFi.status() != WL_CONNECTED) {
    ++loopCounter;    // increment the loop counter
    // have we looped the configured number of times?
    if (loopCounter > WIFI_TIMEOUT) {
      // Get out of the while loop
      Serial.println("\nWi-Fi connection timed out");
      break;
    }
    delay(1000);
    Serial.print(".");
  }

  // Are we connected?
  if (WiFi.status() == WL_CONNECTED) {
    Serial.print("\nConnected, IP address: ");
    Serial.println(WiFi.localIP());
    // Update the RTC from the network
    timeClient.begin();
    timeClient.setTimeOffset(GMT_OFFSET);
    getNetworkTime();
    // get the updated time
    theTime = getAdjustedTime();
    // write it to the monitor
    printTimeValue(theTime);
  }

  // Set the current minute (used to decide when to display the time on the monitor)
  lastMinute = rtc.now().minute();

  // Turn off all of the LEDS
  clearDisplay();

  // Now set things up for displaying the word clock
  matrix.setBrightness(DAYBRIGHTNESS);
  // startup sequence... do colorwipe?
  //  delay(500);
  //  rainbowCycle(1);
  delay(500);
  flashWords(); // briefly flash each word in sequence
  delay(500);
}

void loop() {
  // What's the current time (according to the RTC)?
  DateTime theTime = getAdjustedTime();

  // Did the minute just change?
  if (theTime.minute() != lastMinute) {
    // Then update the last minute variable so we don't run this again
    // this minute
    lastMinute = theTime.minute();
    printTimeValue(theTime);

    // Check the Wi-Fi connection (and reconnect if
    // necessary) every 5 minutes
    if (WiFi.status() != WL_CONNECTED) {
      Serial.println("Wi-Fi not connected");
      if (theTime.minute() % 5 == 0) {
        Serial.println("Retrying Wi-Fi connection");
        WiFi.reconnect();
      }
    }

    // Are we connected to the network?
    if (WiFi.status() == WL_CONNECTED) {
      // is it just after midnight?
      if (theTime.hour() == 0 && theTime.minute() == 1) {
        // then update the RTC From the network
        getNetworkTime();
        // retrieve the updated time (to use in the rest of the loop)
        // since we're assuming it was just updated from the network
        theTime = getAdjustedTime();
        printTimeValue(theTime);
      }
    }
  }

  // Set the LED brightness based on time of day
  adjustBrightness(theTime);
  // and update the display with the new time
  displayTime(theTime);

  // uncomment to show moon mode instead!
  //mode_moon(theTime);
}

void clearDisplay() {
  matrix.fillScreen(0);
  matrix.show();
}

DateTime getAdjustedTime() {
  DateTime theTime;
  theTime = dst_rtc.calculateTime(rtc.now()); // takes into account DST
  return theTime;
}

void getNetworkTime() {
  Serial.println("Getting network time...");
  // Illuminate the first T in the matrix in green when checking network time
  clearDisplay();
  matrix.setPixelColor(LETTER_T, 255, 0, 0);
  matrix.show();
  // Now check the network for the current time
  if (timeClient.forceUpdate()) {
    // NTPClient returned true; so we must have gotten a time
    Serial.println("Updating RTC");
    // Set the clock with the retrieved network time
    rtc.adjust(timeClient.getEpochTime());
  } else {
    Serial.println("Unable to get time from NTP server (not sure why)");
    // Fill the matrix with RED
    matrix.fillScreen(matrix.Color(0, 255, 0));
    matrix.show();
    delay(2000);
  }
  clearDisplay();
}

void printTimeValue(DateTime timeVal) {
#ifdef USE_US_DATE_TIME_FORMAT
  // Get the hour in 12 hour format
  int theHour;
  theHour = timeVal.hour();
  if (theHour > 12) {
    theHour -= 12;
  }
  // Build the date/time string
  sprintf(DateAndTimeString, "%02d-%02d-%4d @ %d:%02d ", timeVal.month(), timeVal.day(), timeVal.year(), theHour, timeVal.minute());
  // Append our AM/PM
  if (timeVal.hour() > 12) {
    strcat(DateAndTimeString, "PM");
  } else {
    strcat(DateAndTimeString, "AM");
  }
#else
  // Build the European date/time string
  sprintf(DateAndTimeString, "%4d-%02d-%02d %d:%02d", timeVal.year(), timeVal.month(), timeVal.day(), timeVal.hour(), timeVal.minute());
#endif
  Serial.print(daysOfTheWeek[timeVal.dayOfTheWeek()]);
  Serial.print(", ");
  Serial.println(DateAndTimeString);
}

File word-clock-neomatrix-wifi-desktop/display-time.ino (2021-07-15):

// Generates a mask representing the current time (approximately) as
// a phrase (through the letters illiminated by the turned-on LED
// in the NeoMatrix
void displayTime(DateTime theTime) {
  /*
   * The capitalized values used below are defines (compiler constants)        
   * which are replaced at compile time with the defined value which,        
   * in this case, is a logical OR of the existing `mask` value with        
   * the number value in the define. The result of this is that the        
   * code repeatedly ORs the current mask with the different word        
   * values as the code completes this big, huge, if/then statement
   *         
   * At the end of the process, the mask value contains an array
   * highlighting all of the NeoPixel LEDs that should be turned   
   * on to display the complete phrase on the NeoMatrix.
  */
  
  // time we display the appropriate theTime.minute() counter
  if ((theTime.minute() > 4) && (theTime.minute() < 10)) {
    MFIVE;
    //Serial.print("five");
  }
  if ((theTime.minute() > 9) && (theTime.minute() < 15)) {
    MTEN;
    //Serial.print("ten");
  }
  if ((theTime.minute() > 14) && (theTime.minute() < 20)) {
    AQUARTER;
    //Serial.print("a quarter");
  }
  if ((theTime.minute() > 19) && (theTime.minute() < 25)) {
    TWENTY;
    //Serial.print("twenty");
  }
  if ((theTime.minute() > 24) && (theTime.minute() < 30)) {
    TWENTY;
    MFIVE;
    //Serial.print("twenty five");
  }
  if ((theTime.minute() > 29) && (theTime.minute() < 35)) {
    HALF;
    //Serial.print("half");
  }
  if ((theTime.minute() > 34) && (theTime.minute() < 40)) {
    TWENTY;
    MFIVE;
    //Serial.print("twenty five");
  }
  if ((theTime.minute() > 39) && (theTime.minute() < 45)) {
    TWENTY;
    //Serial.print("twenty");
  }
  if ((theTime.minute() > 44) && (theTime.minute() < 50)) {
    AQUARTER;
    //Serial.print("a quarter");
  }
  if ((theTime.minute() > 49) && (theTime.minute() < 55)) {
    MTEN;
    //Serial.print("ten");
  }
  if (theTime.minute() > 54) {
    MFIVE;
    //Serial.print("five");
  }

  if ((theTime.minute() < 5))
  {
    switch (theTime.hour()) {
      case 1:
      case 13:
        ONE;
        break;
      case 2:
      case 14:
        TWO;
        break;
      case 3:
      case 15:
        THREE;
        break;
      case 4:
      case 16:
        FOUR;
        break;
      case 5:
      case 17:
        FIVE;
        break;
      case 6:
      case 18:
        SIX;
        break;
      case 7:
      case 19:
        SEVEN;
        break;
      case 8:
      case 20:
        EIGHT;
        break;
      case 9:
      case 21:
        NINE;
        break;
      case 10:
      case 22:
        TEN;
        break;
      case 11:
      case 23:
        ELEVEN;
        break;
      case 0:
      case 12:
        TWELVE;
        break;
    }
  }  else if ((theTime.minute() < 35) && (theTime.minute() > 4))  {
    PAST;
    //Serial.print(" past ");
    switch (theTime.hour()) {
      case 1:
      case 13:
        ONE;
        break;
      case 2:
      case 14:
        TWO;
        break;
      case 3:
      case 15:
        THREE;
        break;
      case 4:
      case 16:
        FOUR;
        break;
      case 5:
      case 17:
        FIVE;
        break;
      case 6:
      case 18:
        SIX;
        break;
      case 7:
      case 19:
        SEVEN;
        break;
      case 8:
      case 20:
        EIGHT;
        break;
      case 9:
      case 21:
        NINE;
        break;
      case 10:
      case 22:
        TEN;
        break;
      case 11:
      case 23:
        ELEVEN;
        break;
      case 0:
      case 12:
        TWELVE;
        break;
    }
  }  else  {
    // if we are greater than 34 minutes past the hour then display
    // the next hour, as we will be displaying a 'to' sign
    TO;
    //Serial.print(" to ");
    switch (theTime.hour()) {
      case 1:
      case 13:
        TWO;
        break;
      case 14:
      case 2:
        THREE;
        break;
      case 15:
      case 3:
        FOUR;
        break;
      case 4:
      case 16:
        FIVE;
        break;
      case 5:
      case 17:
        SIX;
        break;
      case 6:
      case 18:
        SEVEN;
        break;
      case 7:
      case 19:
        EIGHT;
        break;
      case 8:
      case 20:
        NINE;
        break;
      case 9:
      case 21:
        TEN;
        break;
      case 10:
      case 22:
        ELEVEN;
        break;
      case 11:
      case 23:
        TWELVE;
        break;
      case 0:
      case 12:
        ONE;
        break;
    }
  }
  applyMask(); // apply phrase mask to colorshift function
}

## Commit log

2021-07-13 Created project
    [wordclock_faceplate_ponoko.dxf]
2021-07-18 Update world-clock-neomatrix-8x8-wifi.ino
    Finished coding everything. It compiles, but I've not tested this on a device yet.
    Added the code to check the NTP Server and update the RTC.
2021-07-19 renamed cutout folder, added feather version folder
    [wordclock_faceplate_ponoko.dxf]
2021-07-21 tested project
    Updated enclosure drawings for the new hardware
    Moved assembly instructions into a separate file
    Moved software instructions into a separate file
    Updated the main readme
    [wordclock_box_feather.dxf]
2021-07-21 added changelog, updated readme, fixed color shift
    [color-functions.ino]
2021-07-22 Added HOST_NAME config variable
    Sets the host name for the device.
2021-07-22 refactored printTimeValue
    Put the println stuff at the end
2021-07-27 Working on assembly instructions
2021-07-27 added assembly pic
2021-07-27 added final assembly
2021-07-31 whacked wall mount files
2021-08-03 Update readme.md
    Updated parts count (nuts) and changed format for nuts/bolts
2021-08-06 working on enclosure assembly docs
2021-08-10 Finished enclosure assembly instructions.
2021-08-10 Update world-clock-neomatrix-wifi-desktop.ino
    I broke the color wheel function, so I moved the display update to enable it again.
2021-08-10 Update world-clock-neomatrix-wifi-desktop.ino
    Speeded up color wheel
2021-08-16 renamed feather enclosure files
    [wordclock_box_feather.dxf]
2022-11-07 renamed folder (fixed typo)
    [color-functions.ino, display-time.ino, moon.ino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]
